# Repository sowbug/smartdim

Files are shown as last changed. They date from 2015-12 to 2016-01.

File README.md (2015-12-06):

SmartDim
===

A timed dimmer for the Ikea JANSJÖ lamp. Using pulse-width modulation, it starts the light at full brightness, waits 30 minutes, then dims gradually to full darkness over 5 minutes. In theory it's good for a kid who wakes up when the parent comes back in to shut off the reading light.

Parts List
===

* One [Ikea JANSJÖ clip lamp](http://www.ikea.com/us/en/catalog/products/30237256/#/20315674). The one I got was item 801.696.36 and it was marked down to $12.99. If it has a 2-pin DIN speaker connector for the power adapter, and the power is 4 volts at 0.75 amps (3 watts), then it ought to work with this project. Be careful and check the voltage. I've seen other lamps in the JANSJÖ series that run on 7 volts, and that voltage will kill this circuit.
* A way to manufacture PCBs. You will, of course, use [OSH Park](https://oshpark.com/).
* Any old N-channel MOSFET in SOT-223 package that can handle a couple of amps. I used the [NDT3055L](https://www.jameco.com/webapp/wcs/stores/servlet/Product_10001_10001_874875_-1), which says it can dissipate 3 watts. I'd have preferred something with more margin for error, but this was available at Jameco will-call.
* An ATTiny85-20SU, which is the SOIC-8 package. Depending on how lazy you are, you can pick a smaller version of this series and figure out how to scrunch down the firmware size.
* A 6-pin AVR ISP.
* Either a [ProtoProg](http://protofusion.org/wordpress/2013/05/open-hardware-pogo-pin-programmer/) connector or an SOIC-8 clip to program the t85. Yeah, I probably could have fit a standard 6-pin header on this board. Sorry about that.
* An 0805 1uF capacitor.
* The standard [Dangerous Prototypes octagon-shaped SMD button](http://dangerousprototypes.com/docs/Partlist#Buttons_and_switches) (ALPS SKQGAKE010) (note the KE010 variant, which has a 3.43N rather than 2.55N operating force, but which is 50 cents cheaper). I usually use the [TD-85XU](http://www.dx.com/p/td-85xu-mini-tact-switches-50-piece-pack-122514#.VmRq-H4rKV4) because you can acquire a lifetime supply for $10, but I wanted something that was easier to find in the dark, and I happened to have some left over from another project. Looking back (to a few hours ago when this project started), I probably should have picked something a little less premium and with even more travel ([take your pick](http://www.dx.com/s/tact+switch)).
* Depending on whether you want to cut the lamp wires, a male and female pair of 2-pin DIN speaker connectors. You can find these on eBay.

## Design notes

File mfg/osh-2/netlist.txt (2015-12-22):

Netlist

Exported from smartdim.sch at 12/21/15 9:11 PM

EAGLE Version 7.5.0 Copyright (c) 1988-2015 CadSoft

Net        Part     Pad      Pin        Sheet

+5V        C1       1        1          1
           ICSP     6        VCC        1
           JP1      1        1          1
           JP2      1        1          1
           U1       8        VCC        1

GND        C1       2        2          1
           ICSP     5        GND        1
           JP1      2        2          1
           Q1       3        S          1
           SW1      3        3          1
           SW1      4        4          1
           U1       4        GND        1

MISO       ICSP     3        MISO       1
           U1       6        PB1(MISO)  1

MOSI/PWM   ICSP     2        MOSI       1
           Q1       1        G          1
           U1       5        PB0(MOSI)  1

NRES       ICSP     1        \RST       1
           U1       1        PB5(NRES)  1

PWM_VSS    JP2      2        2          1
           Q1       2        D          1
           Q1       4        D          1

SCK        ICSP     4        SCK        1
           U1       7        PB2(SCK/ADC1) 1

USER_INPUT SW1      1        1          1
           SW1      2        2          1
           U1       2        PB3(ADC3)  1

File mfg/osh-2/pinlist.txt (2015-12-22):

Pinlist

Exported from smartdim.sch at 12/21/15 9:12 PM

EAGLE Version 7.5.0 Copyright (c) 1988-2015 CadSoft

Part     Pad      Pin        Dir      Net

C1       1        1          pas      +5V
         2        2          pas      GND

ICSP     1        \RST       io       NRES
         2        MOSI       io       MOSI/PWM
         3        MISO       io       MISO
         4        SCK        io       SCK
         5        GND        io       GND
         6        VCC        io       +5V

JP1      1        1          pas      +5V
         2        2          pas      GND

JP2      1        1          pas      +5V
         2        2          pas      PWM_VSS

Q1       1        G          pas      MOSI/PWM
         2        D          pas      PWM_VSS
         3        S          pas      GND
         4        D          pas      PWM_VSS

SW1      1        1          pas      USER_INPUT
         2        2          pas      USER_INPUT
         3        3          pas      GND
         4        4          pas      GND

U1       1        PB5(NRES)  io       NRES
         2        PB3(ADC3)  io       USER_INPUT
         3        PB4(ADC2)  io                *** unconnected ***
         4        GND        io       GND
         5        PB0(MOSI)  io       MOSI/PWM
         6        PB1(MISO)  io       MISO
         7        PB2(SCK/ADC1) io       SCK
         8        VCC        io       +5V

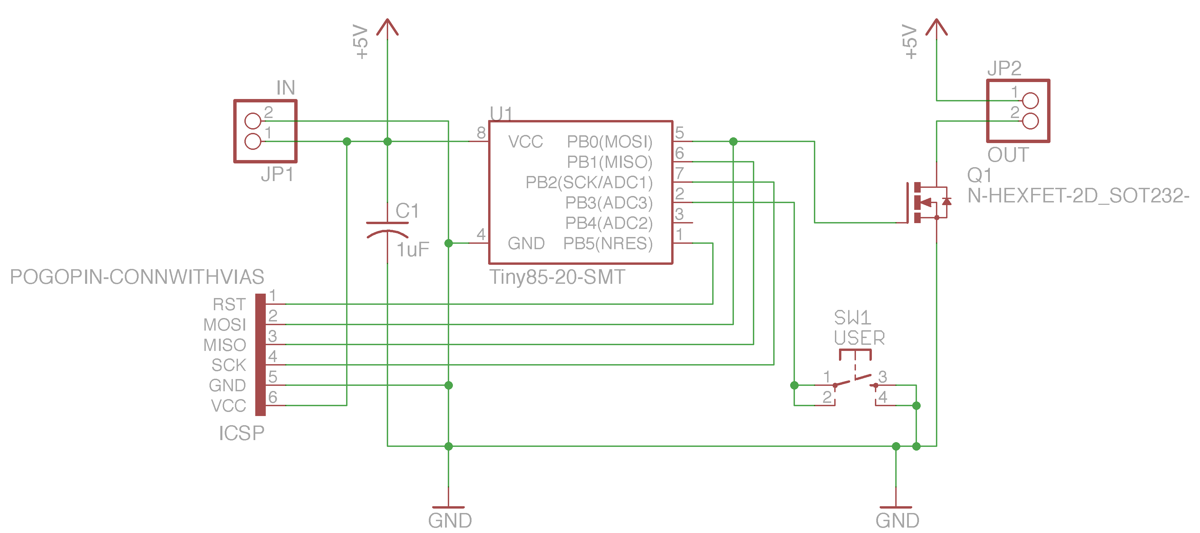
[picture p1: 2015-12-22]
mfg/osh-2/schematic.png

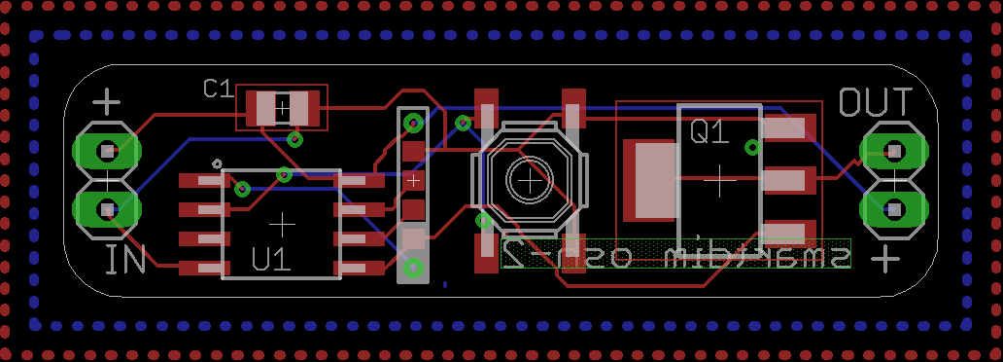
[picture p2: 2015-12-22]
mfg/osh-2/board.png

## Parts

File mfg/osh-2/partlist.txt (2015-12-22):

Partlist

Exported from smartdim.sch at 12/21/15 9:12 PM

EAGLE Version 7.5.0 Copyright (c) 1988-2015 CadSoft

Assembly variant: 

Part     Value                Device                Package          Library            Sheet

C1       1uF                  C-USC0805             C0805            rcl                1
ICSP     POGOPIN-CONNWITHVIAS POGOPIN-CONNWITHVIAS  POGOPROG-CONN-0H Protofusion        1
JP1      IN                   PINHD-1X2             1X02             pinhead            1
JP2      OUT                  PINHD-1X2             1X02             pinhead            1
Q1       N-HEXFET-2D_SOT232-  N-HEXFET-2D_SOT232-   SOT223           transistor-power   1
SW1      USER                 SW_TACT_4P            SW_TACT_SMALL    dp_devices         1
U1       Tiny85-20-SMT        ATTINY45TINY85-20-SMT SO08-EIAJ        SparkFun-DigitalIC 1

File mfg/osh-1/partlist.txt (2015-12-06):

Partlist

Exported from smartdim.sch at 12/5/15 6:41 PM

EAGLE Version 7.5.0 Copyright (c) 1988-2015 CadSoft

Assembly variant: 

Part     Value                Device                Package          Library            Sheet

C1       1uF                  C-USC0805             C0805            rcl                1
ICSP     POGOPIN-CONNWITHVIAS POGOPIN-CONNWITHVIAS  POGOPROG-CONN-0H Protofusion        1
JP1                           PINHD-1X2             1X02             pinhead            1
JP2                           PINHD-1X2             1X02             pinhead            1
Q1       N-HEXFET-2D_SOT232-  N-HEXFET-2D_SOT232-   SOT223           transistor-power   1
SW1                           SW_TACT_4P            SW_TACT_SMALL    dp_devices         1
U1       Tiny85-20-SMT        ATTINY45TINY85-20-SMT SO08-EIAJ        SparkFun-DigitalIC 1

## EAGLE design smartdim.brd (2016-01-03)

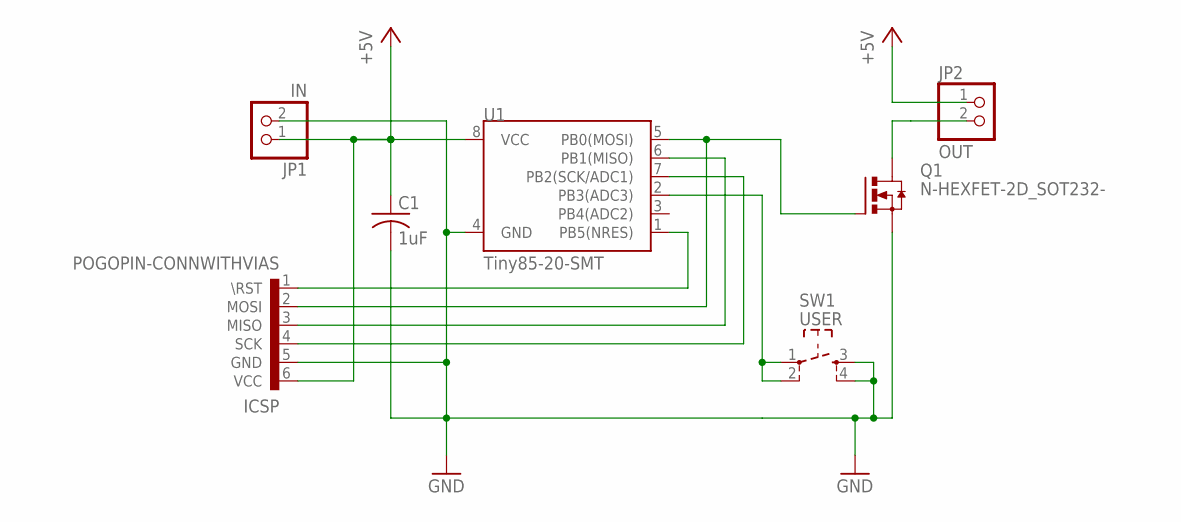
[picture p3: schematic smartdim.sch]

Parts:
C1: 1uF; C0805
ICSP: POGOPIN-CONNWITHVIAS; POGOPROG-CONN-0H
JP1: IN; 1X02
JP2: OUT; 1X02
Q1: N-HEXFET-2D_SOT232-; SOT223
SW1: USER; SW_TACT_SMALL
U1: Tiny85-20-SMT; SO08-EIAJ

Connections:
+5V: C1.1, ICSP.6 (VCC), JP1.1, JP2.1, U1.8 (VCC)
GND: C1.2, ICSP.5 (GND), JP1.2, Q1.3 (S), SW1.3, SW1.4, U1.4 (GND)
MISO: ICSP.3 (MISO), U1.6 (PB1(MISO))
MOSI/PWM: ICSP.2 (MOSI), Q1.1 (G), U1.5 (PB0(MOSI))
NRES: ICSP.1 (\RST), U1.1 (PB5(NRES))
PWM_VSS: JP2.2, Q1.2 (D), Q1.4 (D)
SCK: ICSP.4 (SCK), U1.7 (PB2(SCK/ADC1))
USER_INPUT: SW1.1, SW1.2, U1.2 (PB3(ADC3))

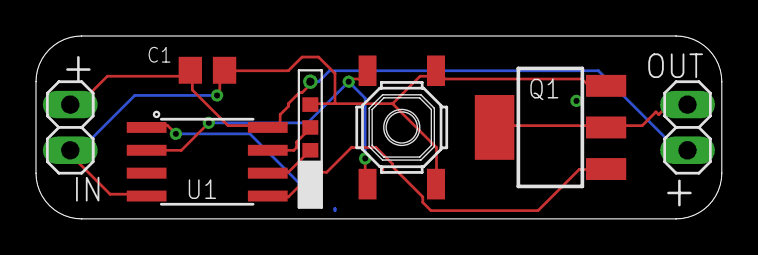
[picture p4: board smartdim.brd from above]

Board: 2 copper layers, 38.1 x 10.2 mm, 7 parts (0 on the bottom side), 8 nets.

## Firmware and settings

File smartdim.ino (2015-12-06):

#define PWM_PIN (0)
#define BUTTON_PIN (3)

// Full-bright duty cycle, where 0 = 0% and 255 = 100%
#define MAX_BRIGHTNESS (0xc0)

// How long the light stays on at full brightness
#define ON_DURATION_MSEC (15 * 60 * 1000)

// How long the dim phase lasts
#define DIM_DURATION_MSEC (5 * 60 * 1000)

// The amount of time we'll delay at a single time in the
// main loop. Larger makes the button less responsive.
// Shorter could theoretically use more power, but probably
// not and even if it does, it doesn't matter.
#define DELAY_MSEC (5)

enum {
  STATE_ON = 0,
  STATE_DIMMING,
  STATE_OFF
};

int state = STATE_ON;
int state_msec_remaining = ON_DURATION_MSEC;
int current_duty_cycle = MAX_BRIGHTNESS;
// see below about pullup & why button is normally high
int last_button_state = HIGH;

void setup() {
  pinMode(PWM_PIN, OUTPUT);

  // http://forum.arduino.cc/index.php?topic=142041.0
  // INPUT_PULLUP means the pin is normally in a HIGH state when
  // unconnected to anything.
#ifdef INPUT_PULLUP
  pinMode(BUTTON_PIN, INPUT_PULLUP);
#else
  // https://digistump.com/board/index.php?topic=1430.0
  pinMode(BUTTON_PIN, INPUT);
  digitalWrite(BUTTON_PIN, HIGH);
#endif

  // fade-on the light at startup
  for (current_duty_cycle = 0;
       current_duty_cycle <= MAX_BRIGHTNESS;
       current_duty_cycle++) {
    analogWrite(PWM_PIN, current_duty_cycle);
    delay(5);  // 5 * 192 = 960 milliseconds
  }
}

void loop() {
  switch (state) {
    case STATE_ON:
      delay(DELAY_MSEC);
      state_msec_remaining -= DELAY_MSEC;
      if (state_msec_remaining <= 0) {
        state = STATE_DIMMING;
      }
      break;
    case STATE_DIMMING:
      analogWrite(PWM_PIN, current_duty_cycle);
      if (--current_duty_cycle <= 0) {
        state = STATE_OFF;
      }
      delay(DIM_DURATION_MSEC / MAX_BRIGHTNESS);  // 1562 msec
      break;
    case STATE_OFF:
      // Just to be sure
      current_duty_cycle = 0;
      analogWrite(PWM_PIN, current_duty_cycle);
      break;
  }

  // This is incomplete. It simply flickers the light
  // when the button is pressed. As an exercise to the reader,
  // introduce more states.
  int current_button_state = digitalRead(BUTTON_PIN);
  if (current_button_state != last_button_state) {
    if (current_button_state == HIGH) {
      for (int i = 0; i < 10; ++i) {
        analogWrite(PWM_PIN, 255);
        delay(20);
        analogWrite(PWM_PIN, 0);
        delay(20);
      }
      analogWrite(PWM_PIN, current_duty_cycle);
    } else {
      // Button is down. Do nothing and wait for it to be
      // released.
    }
    delay(50);  // debounce
    last_button_state = current_button_state;
  }
}

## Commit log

2015-12-06 Remove unnecessary pullup
    [smartdim.brd, smartdim.sch]
2015-12-06 Easier to read labels
    [smartdim.brd]
2015-12-06 Add silkscreen label
    [smartdim.brd]
2015-12-06 New sample sketch
2015-12-22 osh-2: fix swapped MOSFET drain/source
    [smartdim.brd, smartdim.sch]
2016-01-03 IN/OUT were in wrong layer. Fixed
    [smartdim.brd]

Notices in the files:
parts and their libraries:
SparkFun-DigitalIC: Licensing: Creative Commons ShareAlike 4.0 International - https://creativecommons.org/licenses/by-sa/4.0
